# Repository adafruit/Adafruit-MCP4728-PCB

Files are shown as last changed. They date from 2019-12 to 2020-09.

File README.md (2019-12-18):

## Adafruit MCP4728 Quad 12-bit I2C DAC PCB

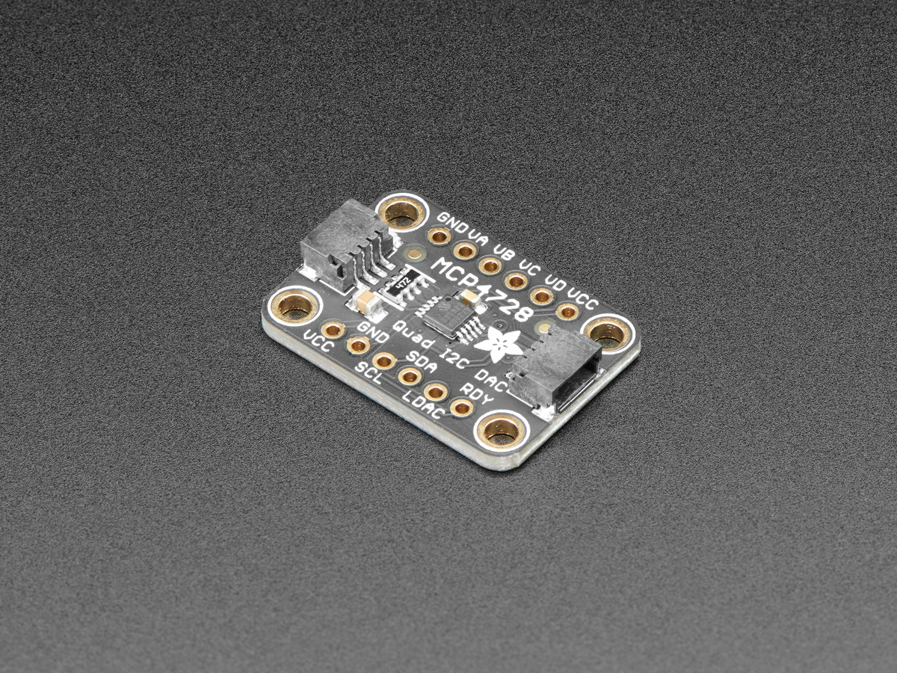
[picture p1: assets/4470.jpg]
<a href="http://www.adafruit.com/products/4470"><br/>
Click here to purchase one from the Adafruit shop</a>

PCB files for the Adafruit MCP4728 Quad 12-bit I2C DAC. 

Format is EagleCAD schematic and board layout
* https://www.adafruit.com/product/4470

### Description

If you've ever said to yourself "Gee, I wish these four 12-bit DACs came in a single package with the ability to save their settings to an EEPROM", well I have good news. The MCP4728 is the answer to your wishes! Within it's little package, the MCP4728 has four, count em, four 12-bit DACs for whatever voltage setting needs you may have. In addition, it has the ability to store the settings for the DACs to an internal EEPROM so you can make like a Ronco Rotisserie and "set it and forget it". Once saved to the internal non-volatile memory, the settings will be loaded by default when the ADC powers up.

To take things even further, the MCP4728 lets you chose between two sources for your reference voltage: the input voltage that you use to power it on the VCC pin, or an internal 2.048V reference voltage. If you use the internal reference voltage (Vref in DAC speak) you can choose between 1X and 2X gain for the output, allowing your voltages to range from 0V to 2.048 or 0V- 4.096V as your application requires. 

By default you'll use the input voltage as your Vref, allowing you to scale the voltages from 0V-3.3V or 5V depending on your input voltage.o

The breakout for the MCP4728 is populated with the required support circuitry to use it with your microcontroller of choice or Blinka-supported computer. The oh-so-easy-to-use ed SparkFun Qwiic compatible STEMMA QT JST SH connectors ease the process of connecting the MCP4728 to your project and allows you to easily share an I2C bus with other STEMMA QT, Quiic, Grove or other compatible sensors.

Our drivers, wiring diagrams, and example code for Arduino, CircuitPython and Python make it easy to get started so you can get rolling with your project instead of futzing with figuring out how to wire things or get the code working. We've got you covered!

### License

Adafruit invests time and resources providing this open source design, please support Adafruit and open-source hardware by purchasing products from [Adafruit](https://www.adafruit.com)!

Designed by Limor Fried/Ladyada for Adafruit Industries.

Creative Commons Attribution/Share-Alike, all text above must be included in any redistribution. 
See license.txt for additional details.

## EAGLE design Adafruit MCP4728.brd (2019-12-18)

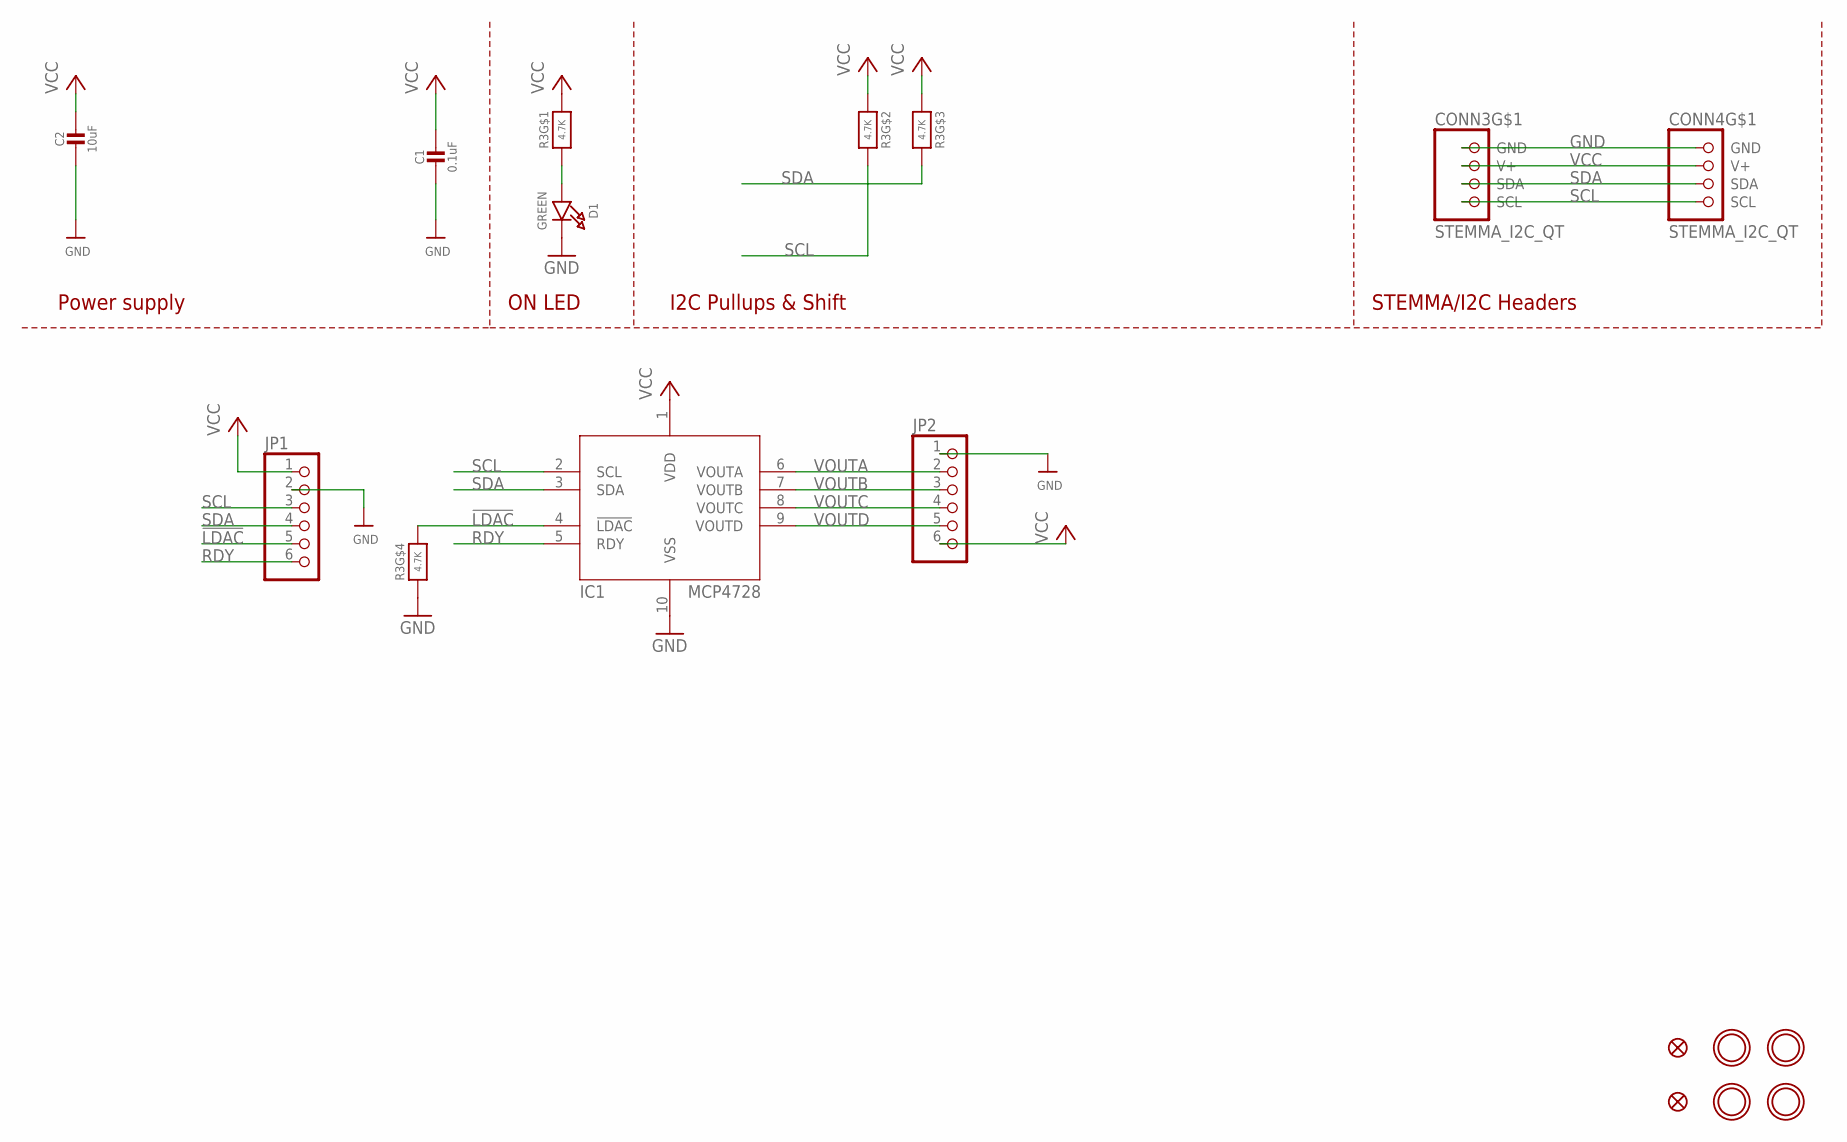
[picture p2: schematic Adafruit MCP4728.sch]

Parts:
C1: 0.1uF; 0603-NO
C2: 10uF; 0805-NO
CONN3, CONN4: STEMMA_I2C_QT; JST_SH4
D1: GREEN; CHIPLED_0603_NOOUTLINE
FID3, FID4: FIDUCIAL_1MM
IC1: MCP4728; MSOP10
JP1, JP2: HEADER-1X670MIL; 1X06_ROUND_70
R3: 4.7K; RESPACK_4X0603
U$1, U$17, U$19, U$21: MOUNTINGHOLE2.5; MOUNTINGHOLE_2.5_PLATED

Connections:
!LDAC: IC1.4 (!LDAC), JP1.5, R3.5 (2)
GND: C1.2, C2.2, CONN3.1 (GND), CONN4.1 (GND), D1.C, IC1.10 (VSS), JP1.2, JP2.1, R3.4 (1)
unnamed: D1.A, R3.1
RDY: IC1.5 (RDY), JP1.6
SCL: CONN3.4 (SCL), CONN4.4 (SCL), IC1.2 (SCL), JP1.3, R3.7 (2)
SDA: CONN3.3 (SDA), CONN4.3 (SDA), IC1.3 (SDA), JP1.4, R3.6 (2)
VCC: C1.1, C2.1, CONN3.2 (V+), CONN4.2 (V+), IC1.1 (VDD), JP1.1, JP2.6, R3.2 (1), R3.3 (1), R3.8 (2)
VOUTA: IC1.6 (VOUTA), JP2.2
VOUTB: IC1.7 (VOUTB), JP2.3
VOUTC: IC1.8 (VOUTC), JP2.4
VOUTD: IC1.9 (VOUTD), JP2.5

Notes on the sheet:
I2C Pullups & Shift
STEMMA/I2C Headers
ON LED
Power supply

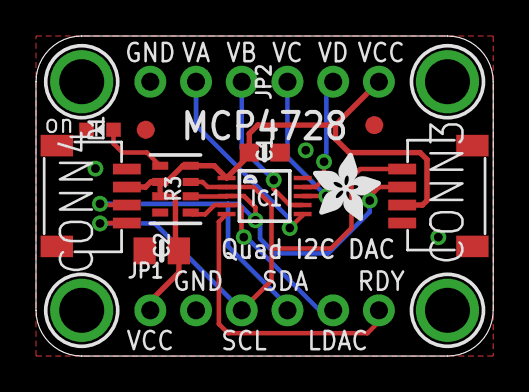
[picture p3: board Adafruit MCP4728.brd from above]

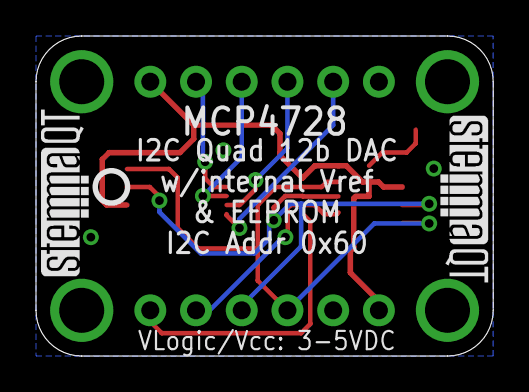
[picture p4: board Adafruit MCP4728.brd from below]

Board: 2 copper layers, 25.4 x 17.8 mm, 19 parts (3 on the bottom side), 11 nets.

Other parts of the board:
U$22: ADAFRUIT_3.5MM
U$25: PCBFEAT-REV-040
U$30, U$31: STEMMAQT

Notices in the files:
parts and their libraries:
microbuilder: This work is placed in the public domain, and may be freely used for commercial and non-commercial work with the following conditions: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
